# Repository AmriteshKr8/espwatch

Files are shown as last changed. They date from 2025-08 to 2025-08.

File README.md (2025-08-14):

# Note:
 - Use 24-30AWG wire for display power lines
 - Only use signal wires for display signals
 - Install all libraries from arduino library manager
 - Move the "User_setup.h" to "arduino sketch folder"/libraries/TFT_eSPI/User_setup.h
 - Edit lines:
     - 185: const char* ap_ssid = "ESPWATCH"; // add your watch hotspot ssid
     - 186: const char* ap_password = "<espwatch-pass>"; // add your hotspot password
     - 249: ESP32Time rtc(19800); // set utc offset in seconds
 - First Setup:
     - Hold the up button
     - Navigate to wifi > host_cp
     - Connect to the hotspot ssid you entered earlier using the password you created
     - Click "Create new file" and create the following files with the given contents, mind the case sensitivity:
          - wpa_creds.txt
            
                <SSID1>:<PASSWORD>
                <SSID2>:<PASSWORD>
  
            Note: You can add a max of 5 different ssids
       
          - battery_stats:
     
                2000
       
            Note: you can enter any number between 1000-2000, it'll be overwritten by the system soon
            
          - weather_cache.txt:
            Note: leave this file blank
            
     - Press Sel on the watch to shut down server
     - Select exit twice to shut the watch down
     - Hold the Sel on the watch, select a network and sync ( it'll take a few tries )
     - Wait for the watch to go to sleep
     - Battery calibration:
       - Charge the battery fully
       - Hold the Sel and down button to boot the watch
       - The temperature reading is replaced by the current battery reading
       - The reading is added to the "battery_status" file automatically
       - Its recommended to calibrate the battery once every few days or optimally after each charge.
- Note:
  - the battery life on this watch is not very good.
  - its very hard to assemble.
  - the watch needs to be synced every time it loses power.
# 3D Files:
- body: https://www.printables.com/model/1381299-espwatch
- Strap: https://www.printables.com/model/1030042-24mm-universal-linked-watch-band

## You Need:

- ### Electronics:
  - Display: https://robu.in/product/goldenmorning-full-color-st7789v-12p-240x280-spi-1-69-inch-tft-lcd-display/
  - SeeedStudio Xiao c3: https://robu.in/product/seeed-studio-xiao-esp32c3-tiny-mcu-board-with-wi-fi-and-ble-battery-charge-supported-power-efficiency-and-rich-interface/
  - Backlight Mosfet: https://robu.in/product/bcp56-hxy-mosfet-80v-1-5w-250150ma2v-1a-npn-sot-223-bipolar-bjt-rohs/
  - Battery: https://robu.in/product/wly402020-120mah-3-7v-single-cell-rechargeable-lipo-battery/
  - Buttons: https://robu.in/product/tact-switch-tvbp06-6-0x3-5mm/
  - Signal wires: https://robu.in/product/0-1mm-copper-soldering-solder-ppa-enamelled-repair-reel-wire/
  - resistors:
      - R1 - 2.2k resistor 1/4w
      - R2/R3 - 10k 1/4w

- ### Strap:
  - Watch Band End Link.stl - 1
  - Watch Band End Link (reversed).stl - 1
  - Watch Band Regular Link.stl - varies depending on wrist size
  - Watch Band Pin Part A.stl - as needed
  - Watch Band Pin Part B.stl - as needed
    
- ### Body:
  - case - 1
  - displaycase - 1
  - xiao-mount - 1
  - backplate - 1
  - button-unmarked - 3
  - cage - 1

# Schematic:


https://easyeda.com/editor#project_id=a65a7b23be7d4b2380da87abd1f7d38c

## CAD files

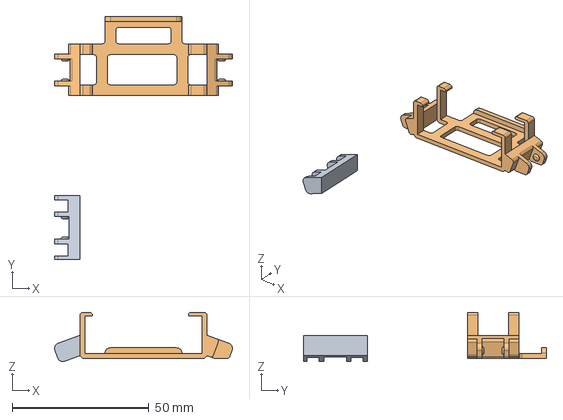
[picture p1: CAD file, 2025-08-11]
Model/espwatch.FCStd
65.0 x 88.8 x 18.0 mm
strap-holder001

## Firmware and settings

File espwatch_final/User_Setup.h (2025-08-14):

//                            USER DEFINED SETTINGS
//   Set driver type, fonts to be loaded, pins used and SPI control method etc.
//
//   See the User_Setup_Select.h file if you wish to be able to define multiple
//   setups and then easily select which setup file is used by the compiler.
//
//   If this file is edited correctly then all the library example sketches should
//   run without the need to make any more changes for a particular hardware setup!
//   Note that some sketches are designed for a particular TFT pixel width/height

// User defined information reported by "Read_User_Setup" test & diagnostics example
#define USER_SETUP_INFO "User_Setup"

// Define to disable all #warnings in library (can be put in User_Setup_Select.h)
//#define DISABLE_ALL_LIBRARY_WARNINGS

// ##################################################################################
//
// Section 1. Call up the right driver file and any options for it
//
// ##################################################################################

// Define STM32 to invoke optimised processor support (only for STM32)
//#define STM32

// Defining the STM32 board allows the library to optimise the performance
// for UNO compatible "MCUfriend" style shields
//#define NUCLEO_64_TFT
//#define NUCLEO_144_TFT

// STM32 8-bit parallel only:
// If STN32 Port A or B pins 0-7 are used for 8-bit parallel data bus bits 0-7
// then this will improve rendering performance by a factor of ~8x
//#define STM_PORTA_DATA_BUS
//#define STM_PORTB_DATA_BUS

// Tell the library to use parallel mode (otherwise SPI is assumed)
//#define TFT_PARALLEL_8_BIT
//#defined TFT_PARALLEL_16_BIT // **** 16-bit parallel ONLY for RP2040 processor ****

// Display type -  only define if RPi display
//#define RPI_DISPLAY_TYPE // 20MHz maximum SPI

// Only define one driver, the other ones must be commented out
//#define ILI9341_DRIVER       // Generic driver for common displays
//#define ILI9341_2_DRIVER     // Alternative ILI9341 driver, see https://github.com/Bodmer/TFT_eSPI/issues/1172
//#define ST7735_DRIVER      // Define additional parameters below for this display
//#define ILI9163_DRIVER     // Define additional parameters below for this display
//#define S6D02A1_DRIVER
//#define RPI_ILI9486_DRIVER // 20MHz maximum SPI
//#define HX8357D_DRIVER
//#define ILI9481_DRIVER
//#define ILI9486_DRIVER
//#define ILI9488_DRIVER     // WARNING: Do not connect ILI9488 display SDO to MISO if other devices share the SPI bus (TFT SDO does NOT tristate when CS is high)
#define ST7789_DRIVER      // Full configuration option, define additional parameters below for this display
//#define ST7789_2_DRIVER    // Minimal configuration option, define additional parameters below for this display
//#define R61581_DRIVER
//#define RM68140_DRIVER
//#define ST7796_DRIVER
//#define SSD1351_DRIVER
//#define SSD1963_480_DRIVER
//#define SSD1963_800_DRIVER
//#define SSD1963_800ALT_DRIVER
//#define ILI9225_DRIVER
//#define GC9A01_DRIVER

// Some displays support SPI reads via the MISO pin, other displays have a single
// bi-directional SDA pin and the library will try to read this via the MOSI line.
// To use the SDA line for reading data from the TFT uncomment the following line:

#define TFT_SDA_READ      // This option is for ESP32 ONLY, tested with ST7789 and GC9A01 display only

// For ST7735, ST7789 and ILI9341 ONLY, define the colour order IF the blue and red are swapped on your display
// Try ONE option at a time to find the correct colour order for your display

//  #define TFT_RGB_ORDER TFT_RGB  // Colour order Red-Green-Blue
#define TFT_RGB_ORDER TFT_BGR  // Colour order Blue-Green-Red

// For M5Stack ESP32 module with integrated ILI9341 display ONLY, remove // in line below

// #define M5STACK

// For ST7789, ST7735, ILI9163 and GC9A01 ONLY, define the pixel width and height in portrait orientation
// #define TFT_WIDTH  80
// #define TFT_WIDTH  128
// #define TFT_WIDTH  172 // ST7789 172 x 320
// #define TFT_WIDTH  170 // ST7789 170 x 320
#define TFT_WIDTH  240 // ST7789 240 x 240 and 240 x 320
// #define TFT_HEIGHT 160
// #define TFT_HEIGHT 128
// #define TFT_HEIGHT 240 // ST7789 240 x 240
#define TFT_HEIGHT 280
// #define TFT_HEIGHT 320 // ST7789 240 x 320
// #define TFT_HEIGHT 240 // GC9A01 240 x 240

// For ST7735 ONLY, define the type of display, originally this was based on the
// colour of the tab on the screen protector film but this is not always true, so try
// out the different options below if the screen does not display graphics correctly,
// e.g. colours wrong, mirror images, or stray pixels at the edges.
// Comment out ALL BUT ONE of these options for a ST7735 display driver, save this
// this User_Setup file, then rebuild and upload the sketch to the board again:

// #define ST7735_INITB
// #define ST7735_GREENTAB
// #define ST7735_GREENTAB2
// #define ST7735_GREENTAB3
// #define ST7735_GREENTAB128    // For 128 x 128 display
// #define ST7735_GREENTAB160x80 // For 160 x 80 display (BGR, inverted, 26 offset)
// #define ST7735_ROBOTLCD       // For some RobotLCD Arduino shields (128x160, BGR, https://docs.arduino.cc/retired/getting-started-guides/TFT)
// #define ST7735_REDTAB
// #define ST7735_BLACKTAB
// #define ST7735_REDTAB160x80   // For 160 x 80 display with 24 pixel offset

// If colours are inverted (white shows as black) then uncomment one of the next
// 2 lines try both options, one of the options should correct the inversion.

#define TFT_INVERSION_ON
// #define TFT_INVERSION_OFF


// ##################################################################################
//
// Section 2. Define the pins that are used to interface with the display here
//
// ##################################################################################

// If a backlight control signal is available then define the TFT_BL pin in Section 2
// below. The backlight will be turned ON when tft.begin() is called, but the library
// needs to know if the LEDs are ON with the pin HIGH or LOW. If the LEDs are to be
// driven with a PWM signal or turned OFF/ON then this must be handled by the user
// sketch. e.g. with digitalWrite(TFT_BL, LOW);

#define TFT_BL   D6            // LED back-light control pin
#define TFT_BACKLIGHT_ON HIGH  // Level to turn ON back-light (HIGH or LOW)
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

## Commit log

2025-08-11 modified files
    [espwatch-backplate.3mf, espwatch-button-down.3mf, espwatch-button-select.3mf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]
2025-08-11 fixed folder structure, removed models and moves them to printables
    [espwatch-backplate.3mf, espwatch-button-down.3mf, espwatch-button-select.3mf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]
2025-08-11 added model source
    [espwatch.FCStd]
